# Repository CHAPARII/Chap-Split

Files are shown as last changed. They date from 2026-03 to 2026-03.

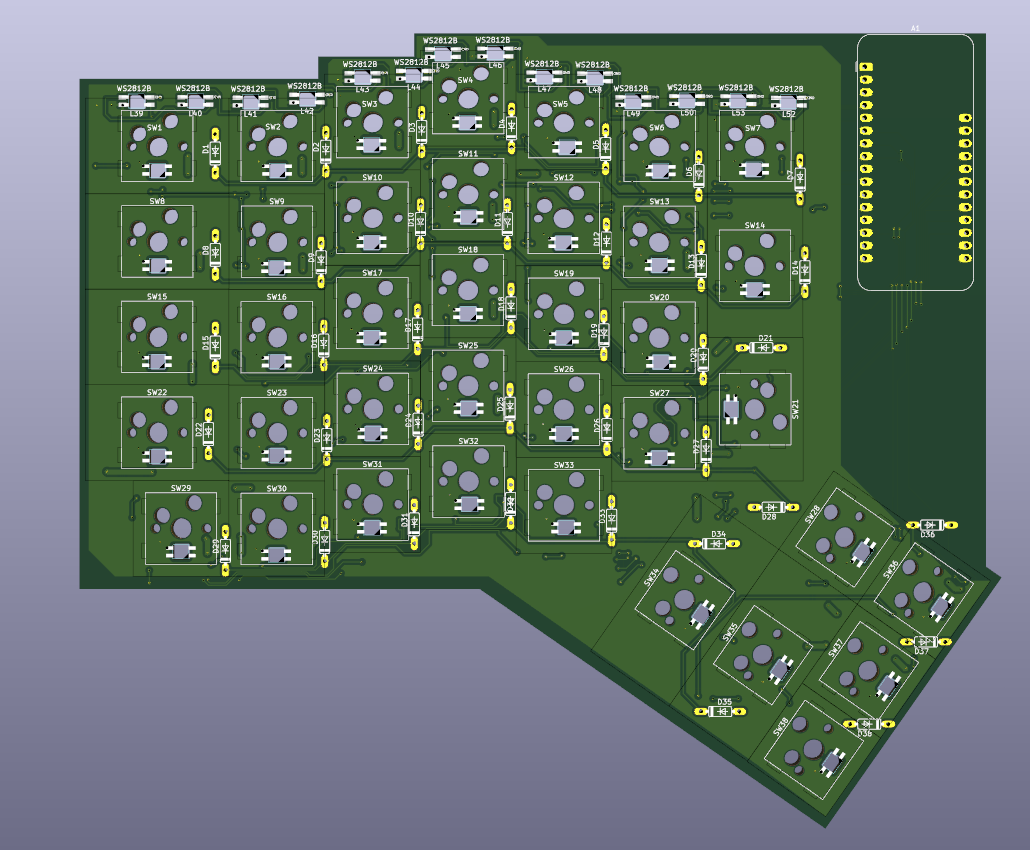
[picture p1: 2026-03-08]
images/Screenshot 2026-03-08 011458.png

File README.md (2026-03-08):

# Split Mechanical Keyboard

The keyboard uses a split layout with around 76 keys, The design is meant to be customizable and DIY-friendly. It uses Kailh hot-swap sockets, which means switches can be replaced anytime without needing to desolder them. This makes it easy to experiment with different switches later. For the controller, I used the nRF52840 development board, which works well with ZMK firmware. ZMK alows the keyboard to support Bluetooth, so it can be used wirelessly. It also support customizable keymaps, layers, and other advanced keyboard features. 

Designing the PCB took a lot more time than I expected. there were many small issues during routing and schematic checks. I spent quite a lot of time fixing different problems and improving the layout. After several iterations and debugging, the **PCB now finally passes both DRC (Design Rule Check) and ERC (Electrical Rule Check) with 0 errors**. Fixing all those issues took a lot of effort, but it was really satisfying to finally see everything clean in KiCad. The keyboard uses 76 mechanical switches, and each switch has a 1N4148 diode for the key matrix. Stabilizers are used for larger keys, and the switches are mounted using Kailh hot-swap sockets. Keycaps and switchs can be changed depending on personal preference.

One goal of this project was also to keep the build relatively affordable. Based on the current Bill of Materials, the estimated total cost is around ₹11,174 (~$121.54 USD) including PCB manufacturing and other components. I tried my best to keep it in budget, I tried to get maximum thing from one place (amazon) in budget to make things simple and save in shipping charges. Also I'll buy the PCBs locally and it would cost me around $20.

Overall, this project was mainly built for learning, experimenting, and having fun with hardware design. It was a really good experience going through the full PCB design process and understanding how keyboards work internally. If someone finds this project interesting or wants to build their own version of it, that would be really awesome.









## Cart:




## Bill of Materials (BOM) – Split Keyboard

| # | Component | Quantity | Unit Price | Total | Link |
|---|---|---|---|---|---|
| 1 | Kailh Hot-Swap Sockets | 1 pack (~100 pcs) | ₹2124 | ₹2124 | https://www.amazon.in/gp/product/B0GHR248QJ |
| 2 | Mechanical Switches | 76 (1 pack) | ₹1965 | ₹1965 | https://www.amazon.in/gp/product/B0F53HLG5M |
| 3 | Stabilizers | 2 sets | ₹876 | ₹1752 | https://www.amazon.in/gp/product/B0FRN1CF4Q |
| 4 | Keycaps | 2 sets | ₹852 | ₹1704 | https://www.amazon.in/gp/product/B0F3883M9C |
| 5 | 1N4148 Diodes | 1 pack (~100 pcs) | ₹285 | ₹285 | https://www.amazon.in/gp/product/B0FJLP12GX |
| 6 | nRF52840 Microcontroller | 2 | ₹758 | ₹1516 | https://robu.in/product/promicro-nrf52840-development-board/ |
| 7 | PCB (Will buy it locally) | 1 order (2PCB) | $20 | ≈ ₹1838 | — |

---
### Total Estimated Cost

| Item | Cost |
|-----|---|
| Components Total | ₹9,336 |
| PCB | ≈ ₹1,838 |
| **Total Build Cost** | **≈ ₹11,174** (**$121.54 USD**) |

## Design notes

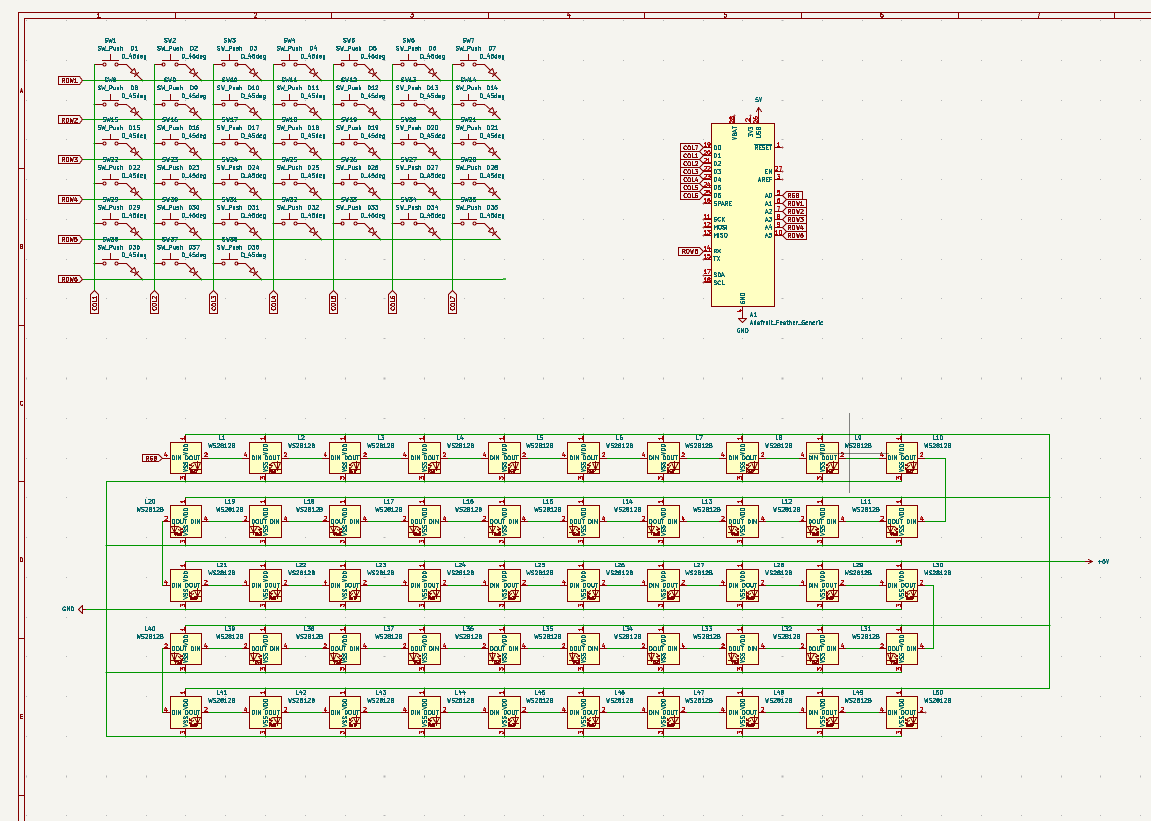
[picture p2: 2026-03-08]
images/Screenshot 2026-03-08 011359.png

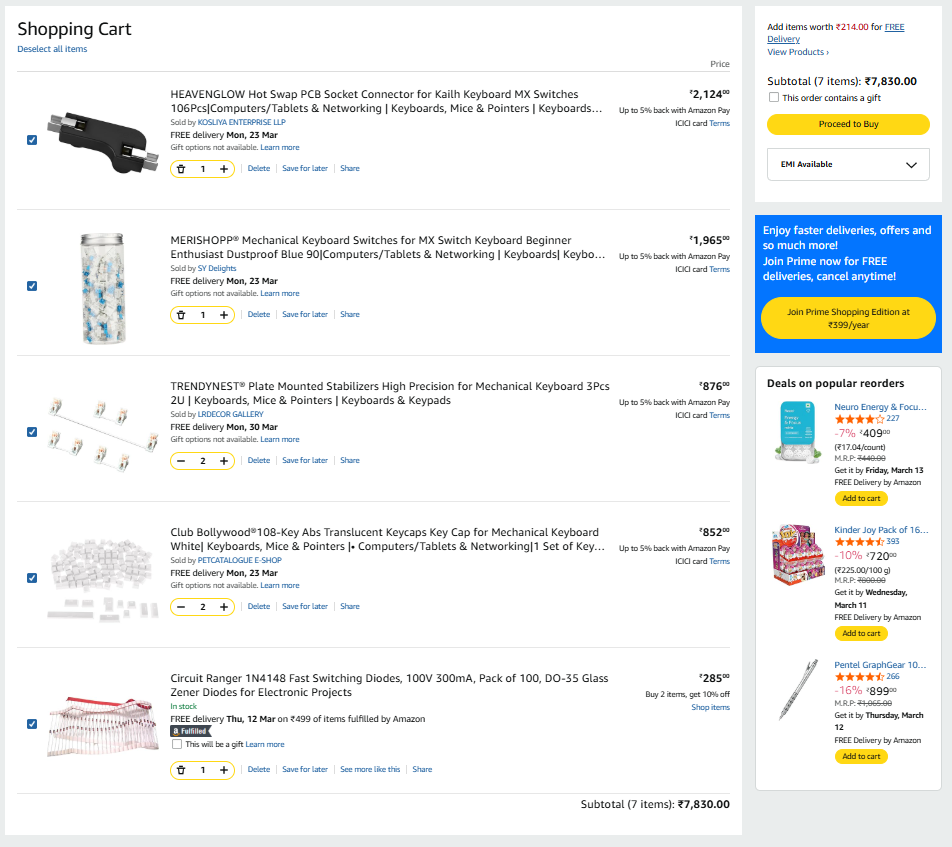
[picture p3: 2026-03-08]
images/Screenshot 2026-03-07 232858.png

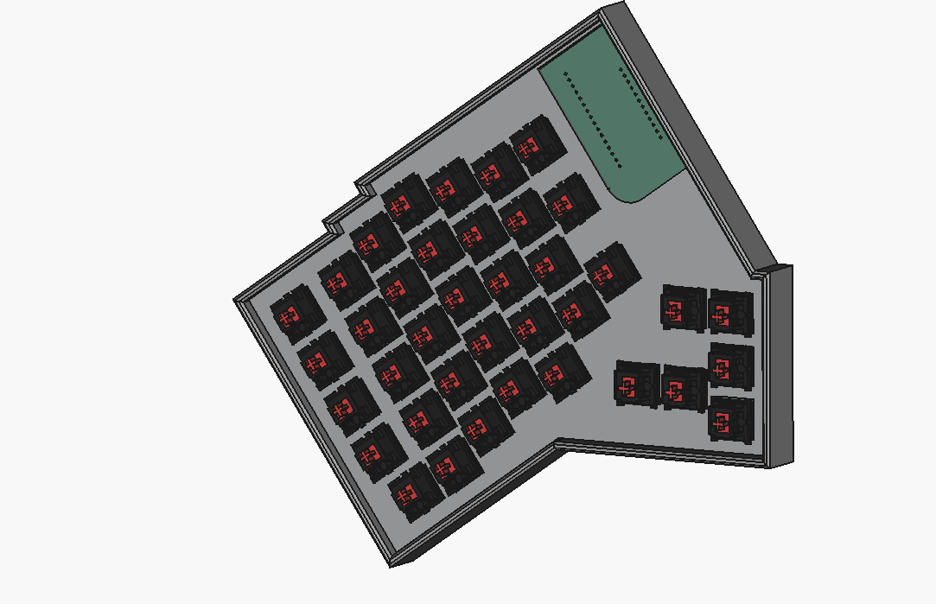
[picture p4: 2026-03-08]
images/Screenshot 2026-03-08 011651.png

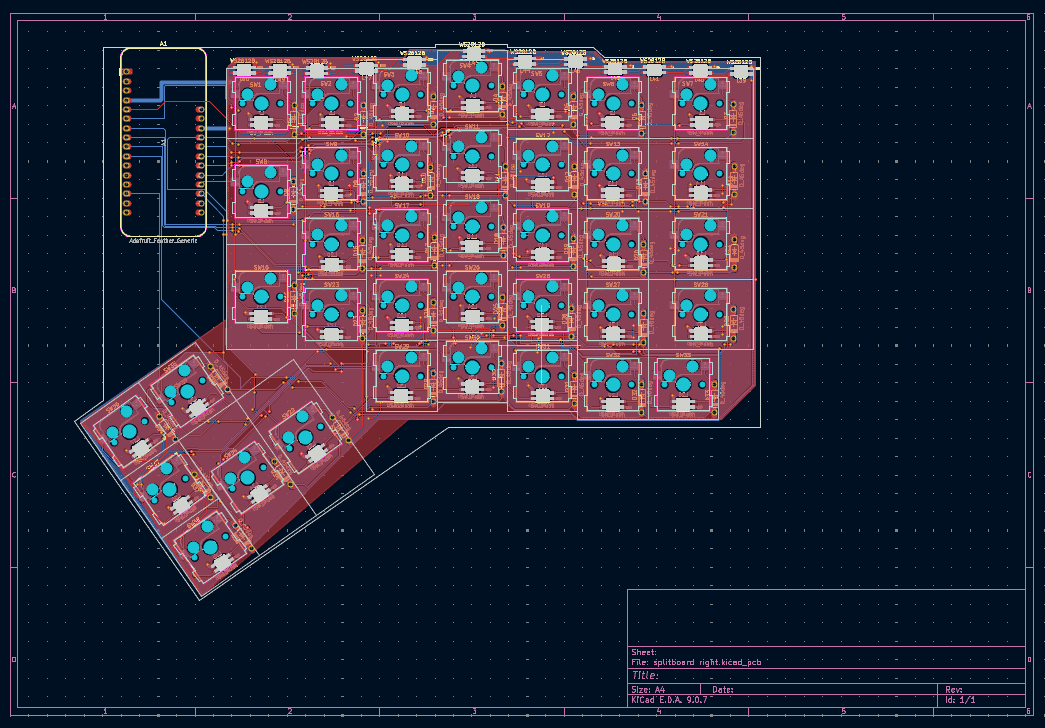
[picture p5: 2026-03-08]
images/Screenshot 2026-03-08 011325.png

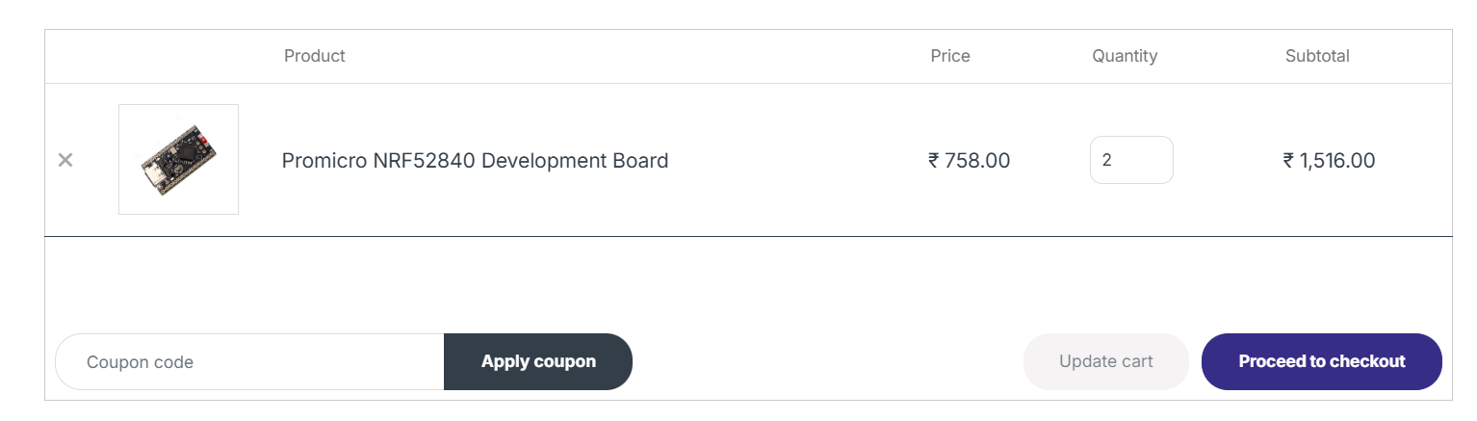
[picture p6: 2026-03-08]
images/Screenshot 2026-03-07 232520.png

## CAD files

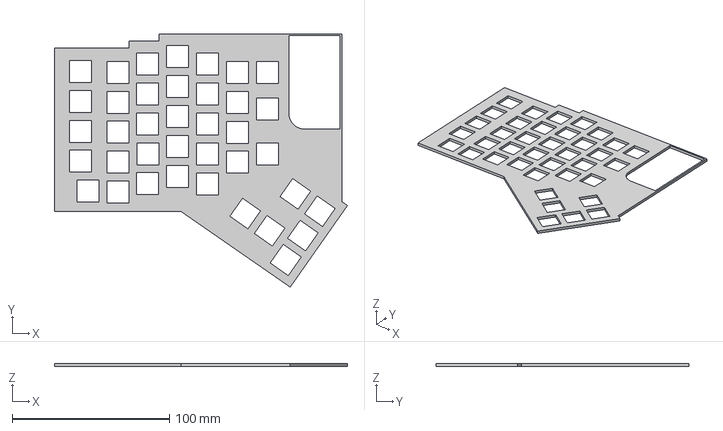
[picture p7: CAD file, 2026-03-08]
CAD/splitboard_left_top v15.step
186.5 x 161.2 x 2.00 mm

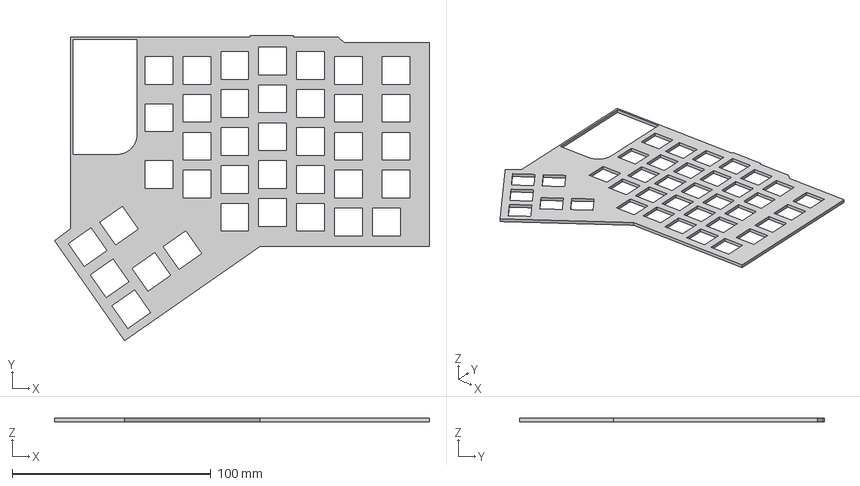
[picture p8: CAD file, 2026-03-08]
CAD/splitboard_right_top v4.step
188.5 x 153.5 x 2.00 mm

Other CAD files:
CAD/splitboard left v11.f3z
CAD/splitboard right v7.f3z

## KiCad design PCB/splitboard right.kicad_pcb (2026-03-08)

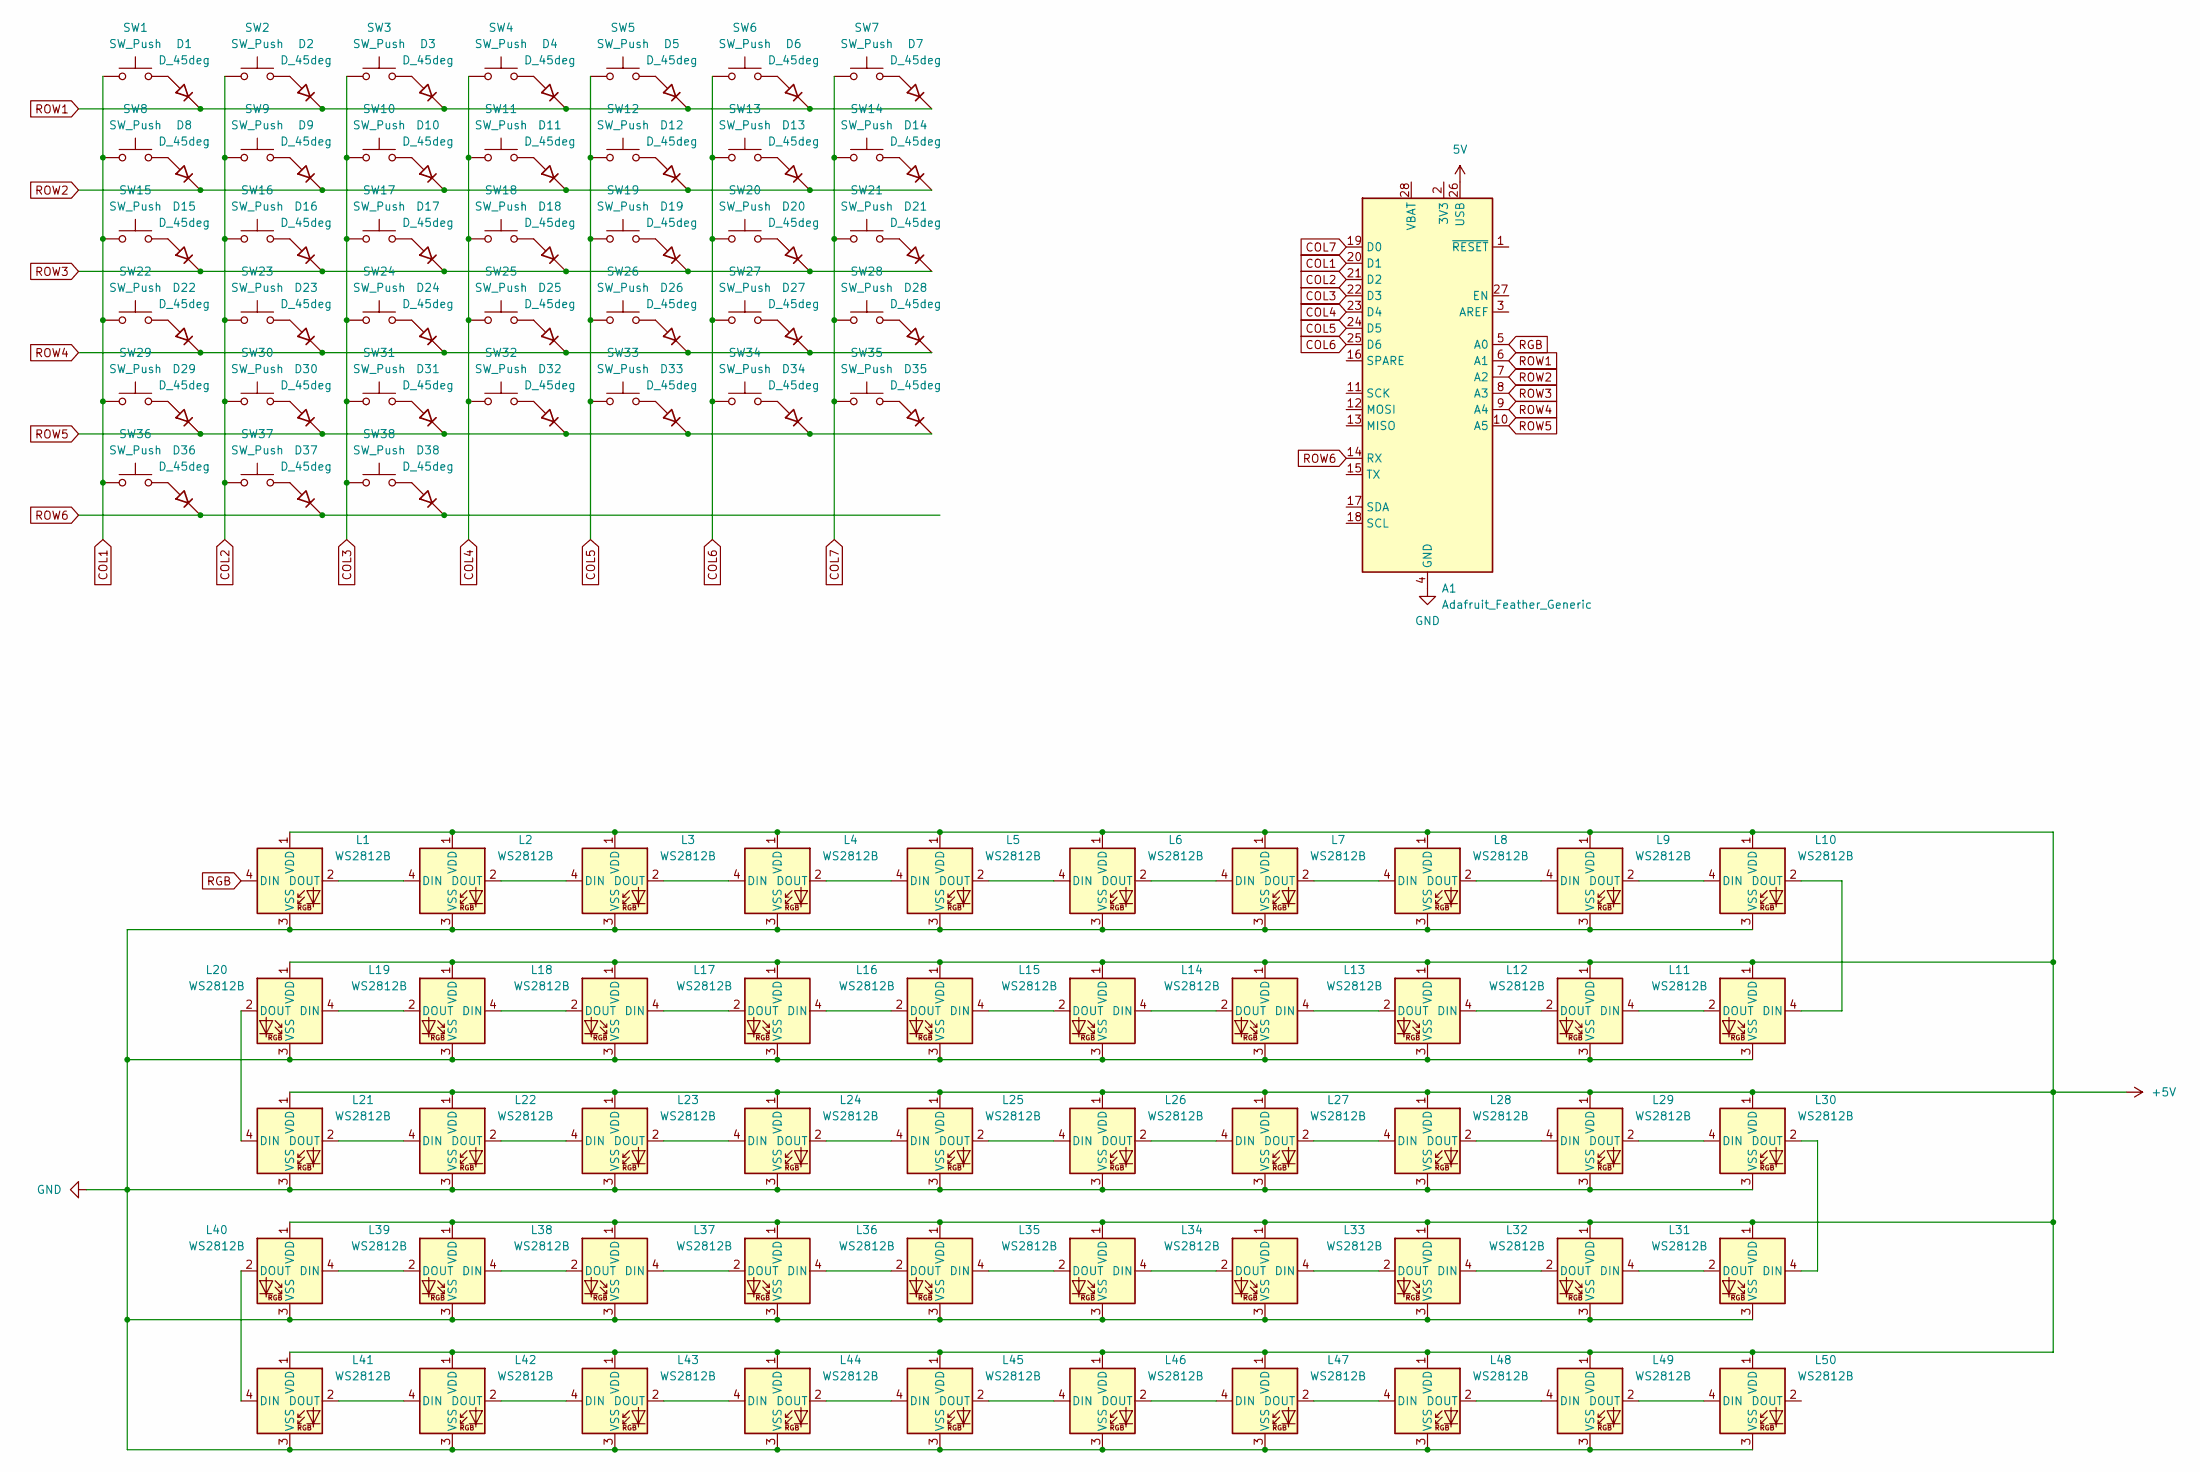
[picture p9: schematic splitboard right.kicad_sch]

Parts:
A1: Adafruit_Feather_Generic; Adafruit_Feather
D1, D2, D3, D4, D5, D6, D7, D8, D9, D10, D11, D12, D13, D14, D15, D16, D17, D18, D19, D20, D21, D22, D23, D24, D25, D26, D27, D28, D29, D30, D31, D32, D33, D34, D35, D36, D37, D38: D_45deg; DO35-7
L1, L2, L3, L4, L5, L6, L7, L8, L9, L10, L11, L12, L13, L14, L15, L16, L17, L18, L19, L20, L21, L22, L23, L24, L25, L26, L27, L28, L29, L30, L31, L32, L33, L34, L35, L36, L37, L38, L39, L40, L41, L42, L43, L44, L45, L46, L47, L48, L49, L50: WS2812B; BAcklight
SW1, SW2, SW3, SW4, SW5, SW6, SW9, SW10, SW11, SW12, SW13, SW16, SW17, SW18, SW19, SW20, SW23, SW24, SW25, SW26, SW27, SW29, SW30, SW31, SW32, SW33, SW35, SW36, SW37, SW38: SW_Push; SW_Hotswap_Kailh_MX_1.00u
SW7, SW14, SW21, SW28: SW_Push; SW_Hotswap_Kailh_MX_1.50u
SW8, SW15: SW_Push; SW_Hotswap_Kailh_MX_1.50u_90deg
SW22, SW34: SW_Push; SW_Hotswap_Kailh_MX_2.00u_90deg

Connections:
COL1: A1.20 (D1), SW1.1, SW8.1, SW15.1, SW22.1, SW29.1, SW36.1
COL2: A1.21 (D2), SW2.1, SW9.1, SW16.1, SW23.1, SW30.1, SW37.1
COL3: A1.22 (D3), SW3.1, SW10.1, SW17.1, SW24.1, SW31.1, SW38.1
COL4: A1.23 (D4), SW4.1, SW11.1, SW18.1, SW25.1, SW32.1
COL5: A1.24 (D5), SW5.1, SW12.1, SW19.1, SW26.1, SW33.1
COL6: A1.25 (D6), SW6.1, SW13.1, SW20.1, SW27.1, SW34.1
COL7: A1.19 (D0), SW7.1, SW14.1, SW21.1, SW28.1, SW35.1
GND: A1.4 (GND), L1.3 (VSS), L2.3 (VSS), L3.3 (VSS), L4.3 (VSS), L5.3 (VSS), L6.3 (VSS), L7.3 (VSS), L8.3 (VSS), L9.3 (VSS), L10.3 (VSS), L11.3 (VSS), L12.3 (VSS), L13.3 (VSS), L14.3 (VSS), L15.3 (VSS), L16.3 (VSS), L17.3 (VSS), L18.3 (VSS), L19.3 (VSS), L20.3 (VSS), L21.3 (VSS), L22.3 (VSS), L23.3 (VSS), L24.3 (VSS), L25.3 (VSS), L26.3 (VSS), L27.3 (VSS), L28.3 (VSS), L29.3 (VSS), L30.3 (VSS), L31.3 (VSS), L32.3 (VSS), L33.3 (VSS), L34.3 (VSS), L35.3 (VSS), L36.3 (VSS), L37.3 (VSS), L38.3 (VSS), L39.3 (VSS), L40.3 (VSS), L41.3 (VSS), L42.3 (VSS), L43.3 (VSS), L44.3 (VSS), L45.3 (VSS), L46.3 (VSS), L47.3 (VSS), L48.3 (VSS), L49.3 (VSS), L50.3 (VSS)
unnamed: D1.2 (A), SW1.2
unnamed: D2.2 (A), SW2.2
unnamed: D3.2 (A), SW3.2
unnamed: D4.2 (A), SW4.2
unnamed: D5.2 (A), SW5.2
unnamed: D6.2 (A), SW6.2
unnamed: D7.2 (A), SW7.2
unnamed: D8.2 (A), SW8.2
unnamed: D9.2 (A), SW9.2
unnamed: D10.2 (A), SW10.2
unnamed: D11.2 (A), SW11.2
unnamed: D12.2 (A), SW12.2
unnamed: D13.2 (A), SW13.2
unnamed: D14.2 (A), SW14.2
unnamed: D15.2 (A), SW15.2
unnamed: D16.2 (A), SW16.2
unnamed: D17.2 (A), SW17.2
unnamed: D18.2 (A), SW18.2
unnamed: D19.2 (A), SW19.2
unnamed: D20.2 (A), SW20.2
unnamed: D21.2 (A), SW21.2
unnamed: D22.2 (A), SW22.2
unnamed: D23.2 (A), SW23.2
unnamed: D24.2 (A), SW24.2
unnamed: D25.2 (A), SW25.2
unnamed: D26.2 (A), SW26.2
unnamed: D27.2 (A), SW27.2
unnamed: D28.2 (A), SW28.2
unnamed: D29.2 (A), SW29.2
unnamed: D30.2 (A), SW30.2
unnamed: D31.2 (A), SW31.2
unnamed: D32.2 (A), SW32.2
unnamed: D33.2 (A), SW33.2
unnamed: D34.2 (A), SW34.2
unnamed: D35.2 (A), SW35.2
unnamed: D36.2 (A), SW36.2
unnamed: D37.2 (A), SW37.2
unnamed: D38.2 (A), SW38.2
unnamed: L1.2 (DOUT), L2.4 (DIN)
unnamed: L2.2 (DOUT), L3.4 (DIN)
unnamed: L3.2 (DOUT), L4.4 (DIN)
unnamed: L4.2 (DOUT), L5.4 (DIN)
unnamed: L5.2 (DOUT), L6.4 (DIN)
unnamed: L6.2 (DOUT), L7.4 (DIN)
unnamed: L7.2 (DOUT), L8.4 (DIN)
unnamed: L8.2 (DOUT), L9.4 (DIN)
unnamed: L9.2 (DOUT), L10.4 (DIN)
unnamed: L10.2 (DOUT), L11.4 (DIN)
unnamed: L11.2 (DOUT), L12.4 (DIN)
unnamed: L12.2 (DOUT), L13.4 (DIN)
unnamed: L13.2 (DOUT), L14.4 (DIN)
unnamed: L14.2 (DOUT), L15.4 (DIN)
unnamed: L15.2 (DOUT), L16.4 (DIN)
unnamed: L16.2 (DOUT), L17.4 (DIN)
unnamed: L17.2 (DOUT), L18.4 (DIN)
unnamed: L18.2 (DOUT), L19.4 (DIN)
unnamed: L19.2 (DOUT), L20.4 (DIN)
unnamed: L20.2 (DOUT), L21.4 (DIN)
unnamed: L21.2 (DOUT), L22.4 (DIN)
unnamed: L22.2 (DOUT), L23.4 (DIN)
unnamed: L23.2 (DOUT), L24.4 (DIN)
unnamed: L24.2 (DOUT), L25.4 (DIN)
unnamed: L25.2 (DOUT), L26.4 (DIN)
unnamed: L26.2 (DOUT), L27.4 (DIN)
unnamed: L27.2 (DOUT), L28.4 (DIN)
unnamed: L28.2 (DOUT), L29.4 (DIN)
unnamed: L29.2 (DOUT), L30.4 (DIN)
unnamed: L30.2 (DOUT), L31.4 (DIN)
unnamed: L31.2 (DOUT), L32.4 (DIN)
unnamed: L32.2 (DOUT), L33.4 (DIN)
unnamed: L33.2 (DOUT), L34.4 (DIN)
unnamed: L34.2 (DOUT), L35.4 (DIN)
unnamed: L35.2 (DOUT), L36.4 (DIN)
unnamed: L36.2 (DOUT), L37.4 (DIN)
unnamed: L37.2 (DOUT), L38.4 (DIN)
unnamed: L38.2 (DOUT), L39.4 (DIN)
unnamed: L39.2 (DOUT), L40.4 (DIN)
unnamed: L40.2 (DOUT), L41.4 (DIN)
unnamed: L41.2 (DOUT), L42.4 (DIN)
unnamed: L42.2 (DOUT), L43.4 (DIN)
unnamed: L43.2 (DOUT), L44.4 (DIN)
unnamed: L44.2 (DOUT), L45.4 (DIN)
unnamed: L45.2 (DOUT), L46.4 (DIN)
unnamed: L46.2 (DOUT), L47.4 (DIN)
unnamed: L47.2 (DOUT), L48.4 (DIN)
unnamed: L48.2 (DOUT), L49.4 (DIN)
unnamed: L49.2 (DOUT), L50.4 (DIN)
RGB: A1.5 (A0), L1.4 (DIN)
ROW1: A1.6 (A1), D1.1 (K), D2.1 (K), D3.1 (K), D4.1 (K), D5.1 (K), D6.1 (K), D7.1 (K)
ROW2: A1.7 (A2), D8.1 (K), D9.1 (K), D10.1 (K), D11.1 (K), D12.1 (K), D13.1 (K), D14.1 (K)
ROW3: A1.8 (A3), D15.1 (K), D16.1 (K), D17.1 (K), D18.1 (K), D19.1 (K), D20.1 (K), D21.1 (K)
ROW4: A1.9 (A4), D22.1 (K), D23.1 (K), D24.1 (K), D25.1 (K), D26.1 (K), D27.1 (K), D28.1 (K)
ROW5: A1.10 (A5), D29.1 (K), D30.1 (K), D31.1 (K), D32.1 (K), D33.1 (K), D34.1 (K), D35.1 (K)
ROW6: A1.14 (RX), D36.1 (K), D37.1 (K), D38.1 (K)

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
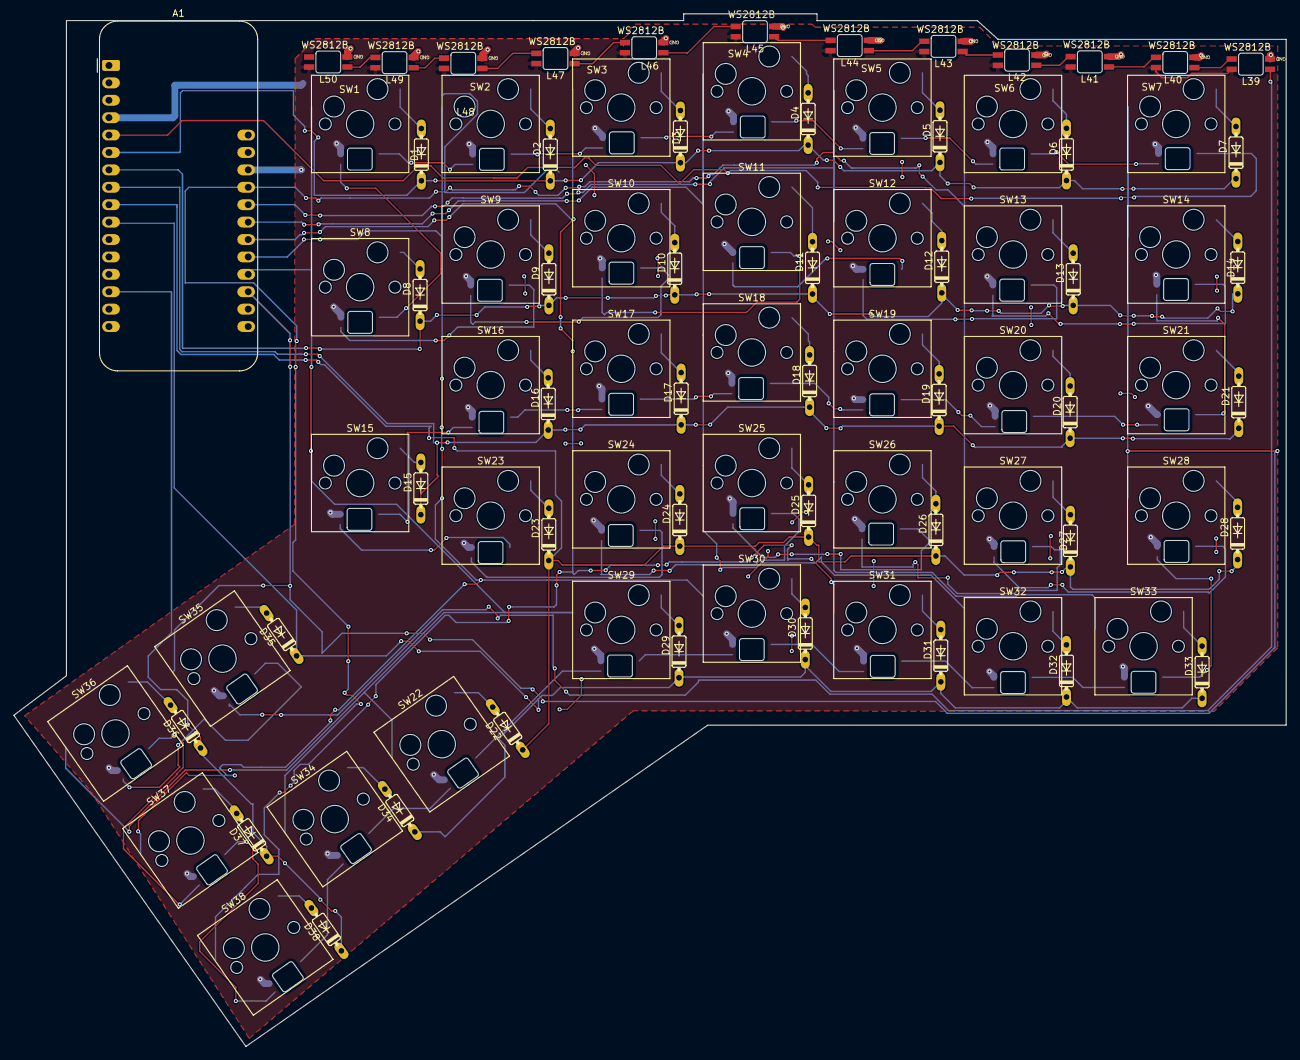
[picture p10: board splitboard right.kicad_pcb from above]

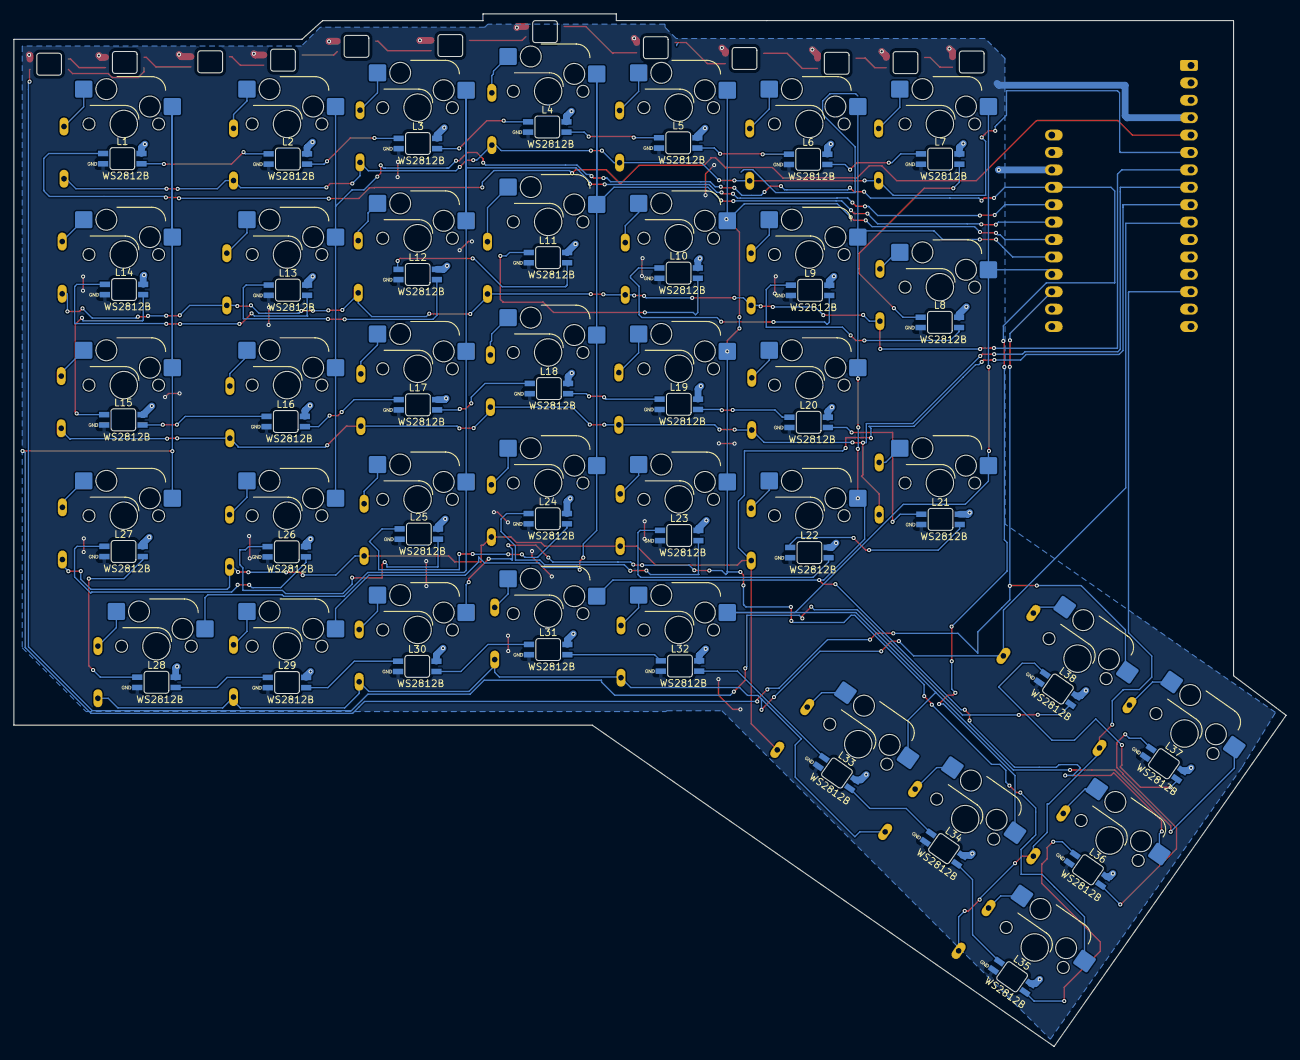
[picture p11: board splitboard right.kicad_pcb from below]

Board: 2 copper layers, 185.6 x 150.6 mm, 127 parts (38 on the bottom side), 103 nets.

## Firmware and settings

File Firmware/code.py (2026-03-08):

import board
import busio

from kmk.kmk_keyboard import KMKKeyboard
from kmk.keys import KC
from kmk.scanners import DiodeOrientation
from kmk.modules.macros import Macros

keyboard = KMKKeyboard()

# from kmk.extensions.display import Display, TextEntry
# from kmk.extensions.LED import LED, AnimationModes
# from kmk.extensions.display.ssd1306 import SSD1306

from kmk.modules.encoder import EncoderHandler

encoder_handler = EncoderHandler()
keyboard.modules = [encoder_handler]

from kmk.extensions.media_keys import MediaKeys
keyboard.extensions.append(MediaKeys())


col_0 = board.GP0  # Column0
col_1 = board.GP1  # Column1
col_2 = board.GP8  # Column2
col_3 = board.GP9  # Column3
col_4 = board.GP12 # Column4
col_5 = board.GP13 # Column5
col_6 = board.GP16 # Column6
col_7 = board.GP17 # Column7
col_8 = board.GP26


row_0 = board.GP2
row_1 = board.GP3
row_2 = board.GP6
row_3 = board.GP7
row_4 = board.GP10
row_5 = board.GP11
row_6 = board.GP14
row_7 = board.GP15
row_8 = board.GP18
row_9 = board.GP19

keyboard.diode_orientation = DiodeOrientation.COL2ROW # the stripe (+) points towards the row 

keyboard.col_pins = (col_0, col_1, col_2, col_3, col_4, col_5, col_6, col_7, col_8);
keyboard.row_pins = (row_0, row_1, row_2, row_3, row_4, row_5, row_6, row_7, row_8, row_9);


keyboard.keymap = [
    [KC.ESC, KC.KP_ASTERISK, KC.F1, KC.F2, KC.F3, KC.F4, KC.F5, KC.F6, KC.F7, KC.F8, KC.F9, KC.F10, KC.F11, KC.F12, KC.PSCREEN, KC.DELETE, KC.KP_4, KC.KP_5, KC.KP_6, KC.KP_3, KC.KP_2, KC.KP_1, KC.N8, KC.N9, KC.N0, KC.MINUS, KC.EQUAL, KC.RBRACKET, KC.GRAVE, KC.N1, KC.N2, KC.N3, KC.N4, KC.N5, KC.N6, KC.N7, KC.Q, KC.W, KC.E, KC.R, KC.T, KC.Y, KC.U, KC.I, KC.O, KC.A, KC.S, KC.D, KC.F, KC.G, KC.H, KC.J, KC.K, KC.L, KC.Z, KC.X, KC.C, KC.V, KC.B, KC.N, KC.M, KC.COMMA, KC.DOT, KC.P, KC.LBRACKET, KC.SCOLON, KC.QUOTE, KC.SLASH, KC.LALT, KC.LEFT, KC.DOWN, KC.RIGHT, KC.KP_7, KC.UP, KC.KP_9, KC.LCTRL, KC.LGUI, KC.RALT, KC.RGUI, KC.RCTRL, KC.TAB, KC.BSLASH, KC.MENU, KC.CAPSLOCK, KC.BSPC, KC.ENTER, KC.LSHIFT, KC.RSHIFT, KC.SPACE, KC.VOLU],  # Row 0
    [KC.F9, KC.F10, KC.F11, KC.F12, KC.PSCREEN, KC.GRAVE, KC.N1, KC.N2, KC.N3],  # row 1 test
    [KC.F1]*9,
    [KC.NO, KC.N1, KC.N2, KC.N3, KC.N4, KC.N5, KC.NO, KC.NO, KC.NO],
    [KC.F2]*9,
    [KC.F3]*9,
    [KC.F4]*9,
    [KC.F5]*9,
    [KC.F6]*9,
    [KC.F7]*9,
]




encoder_handler = EncoderHandler()

encoder_handler.pins = ((board.GP22, board.GP20, None),)


encoder_handler.map = [
    ((KC.VOLD, KC.VOLU, KC.MUTE),), 
]


if __name__ == '__main__':
    keyboard.go()





# d_pin = board.GP8

# oled_bus = busio.I2C(board.GP_SCL, board.GP_SDA)

# oled_driver = SSD1306(i2c=oled_bus, device_address=0x3C);

# display = Display(
#     display=oled_driver,
#     width=128,
#     height=32, 
#     dim_time=10,
#     dim_target=0.2,
#     off_time=1200,
#     brightness=0.8
# );
